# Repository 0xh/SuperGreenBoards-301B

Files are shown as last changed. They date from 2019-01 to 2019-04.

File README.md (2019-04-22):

SuperGreenLab

SuperGreenLab (https://www.reddit.com/r/SuperGreenLab)

# Table of Contents

   * [SuperGreenBoards-301B](#supergreenboards-301b)
   * [SGB.301B Overview](#sgb301b-overview)
   * [Board specifications](#board-specifications)
      * [SGB 36.301B](#sgb-36301b)
      * [SGB 72.301B](#sgb-72301b)
      * [SGB 144.301B](#sgb-144301b)
      * [SB 192.301B](#sb-192301b)
      * [SGB 288.301B](#sgb-288301b)
   * [License](#license)
   * [Creative Commons Warranties Disclaimer](#creative-commons-warranties-disclaimer)

# SuperGreenBoards-301B

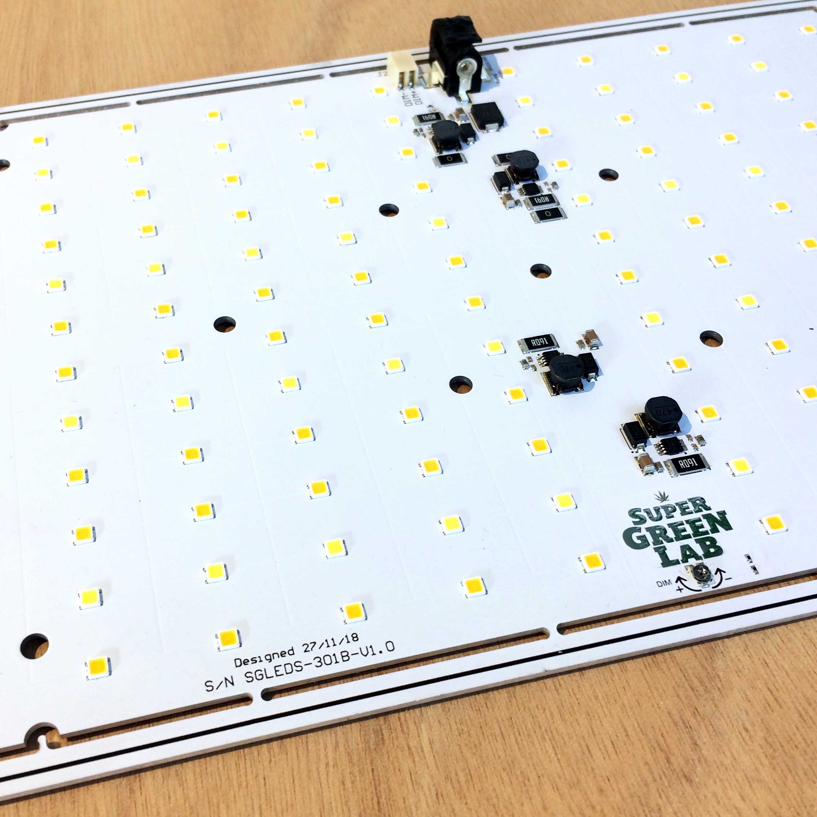
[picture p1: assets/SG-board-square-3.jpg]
SuperGreenLab SuperGreenLeds-301B

First prototype of the SGB.301B family

SGB.301B are aluminium substrate led boards containing up to 288 Samsung's LM301B leds supergreenlab (https://supergreenlab.com/). This open hardware design is licensed under the Creative Commons Attribution-ShareAlike 3.0 Unported License.

Pull requests of relevant issues are warmly welcomed.

# SGB.301B Overview

* **LEDS** : up to 288 Samsung's [LM301B](https://www.samsung.com/led/lighting/mid-power-leds/3030-leds/lm301b/) 220 lm/W, CRI80 leds. Boards are setup with 2/3 2700K leds and 1/3 5000K leds for best grow and flowering performances. (spectum below)
* **ONBOARD LED drivers** (if applicable) : [AL8806MP8-13](https://www.diodes.com/assets/Datasheets/AL8806.pdf) buck step-down, up to 1.5A and 98% efficiency led driver.
* **POWER IN** : Standard 5*2.5mm Barrel/Jack or 3 pins JST-XH [S3B-XH-SM4-TB](http://www.jst-mfg.com/product/detail_e.php?series=277) or [screwless terminal block](https://www.metz-connect.com/us/system/files/productfiles/Data_sheet_SM99S01VBNN04G7_SM99S01VBNN04G7_OFF-031067R.pdf) (see each board specification)
* **DIMMER** : All Boards can be dimmed (see each board specification)
* **ADDITIONAL** : All boards have mouting holes compatible with VESA : 75x75mm, 100x100mm and additional M4 mounting holes on the sides.
* **THERMAL** : Boards are made from Aluminium Substrate panel for best thermal performances. Each boards is designed to be used without heatsink in standard ambient temperature.

**TODO** Add board spectrum

# Board specifications
 
## SGB 36.301B

* **LEDS** : 36 [LM301B](https://www.samsung.com/led/lighting/mid-power-leds/3030-leds/lm301b/) for 4K lumens total
* **ONBOARD LED drivers** : 1 
* **SIZE** : 130mmx110mm (5.1"x4.3")
* **CONNECTOR** : 3 pins JST-XH [S3B-XH-SM4-TB](http://www.jst-mfg.com/product/detail_e.php?series=277) for power and dimmer
* **POWER INPUT** : 24VDC/1A (Constant Voltage), Max Power : 20W. Designed to be powered by supergreenlab's [SGController](https://github.com/supergreenlab/SuperGreenController)
* **DIMMER** : 10V analog or PWM. Designed to be controlled by supergreenlab's [SGController]
* **MOUNTING HOLES** : VESA 75x75mm and 100x100m M4

## SGB 72.301B

* **LEDS** : 72 [LM301B](https://www.samsung.com/led/lighting/mid-power-leds/3030-leds/lm301b/) for 8K lumens total
* **ONBOARD LED drivers** : 2 (36 leds/driver) 
* **SIZE** : 250mmx110mm (9.8"x5.1")
* **CONNECTOR** : 3 pins JST-XH [S3B-XH-SM4-TB](http://www.jst-mfg.com/product/detail_e.php?series=277) for power and dimmer
* **POWER INPUT** : 24VDC/2A (Constant Voltage), Max Power : 40W. Designed to be powered by supergreenlab's [SGController](https://github.com/supergreenlab/SuperGreenController)
* **DIMMER** : 10V analog or PWM. Designed to be controlled by supergreenlab's [SGController](https://github.com/supergreenlab/SuperGreenController)
* **MOUNTING HOLES** : VESA 75x75mm and 100x100m M4, additionnal mounting holes on the side

## SGB 144.301B

* **LEDS** : 144 [LM301B](https://www.samsung.com/led/lighting/mid-power-leds/3030-leds/lm301b/) for 16K lumens total
* **ONBOARD LED drivers** : 4 (36 leds/driver) 
* **SIZE** : 250mmx230mm (9.8"x9")
* **CONNECTOR** : Standard 5*2.5mm Barrel/Jack for power and 3 pins JST-XH [S3B-XH-SM4-TB](http://www.jst-mfg.com/product/detail_e.php?series=277) for power and dimmer
* **POWER** : Input : 24VDC/5A (Constant Voltage Power supply : https://amzn.to/2DNSty4), Max Power : 80W.
* **DIMMER** : 10V analog or PWM. Designed to be controlled by supergreenlab's [SGController](https://github.com/supergreenlab/SuperGreenController)
* **MOUNTING HOLES** : VESA 75x75mm and 100x100m M4, VESA 200x200mm M6, additionnal mounting holes on the side

## SB 192.301B

* **LEDS** : 192 [LM301B](https://www.samsung.com/led/lighting/mid-power-leds/3030-leds/lm301b/) for 20K lumens total
* **ONBOARD LED drivers** : 4 (48 leds/driver) 
* **MCU** : [ESP32-WROOM-32](https://www.espressif.com/en/products/hardware/esp-wroom-32/overview), wifi , bluetooth and BLE microcontroller. Fimrware : [SuperGreenOS](https://github.com/supergreenlab/SuperGreenOS) app : [SuperGreenApp](https://github.com/supergreenlab/SuperGreenApp)
* **SIZE** : 350mmx230mm (13.8"x9")
* **CONNECTOR** : Standard 5*2.5mm Barrel/Jack for power , 2 pins JST-XH [S2B-XH-SM4-TB](http://www.jst-mfg.com/product/detail_e.php?series=277) for Fan/Blower and 4 pins JST-XH [S4B-XH-SM4-TB](http://www.jst-mfg.com/product/detail_e.php?series=277) for sensor
* **POWER** : Input : 24VDC/5A (Constant Voltage Power supply : https://amzn.to/2DNSty4), Max Power : 120W.
* **MOUNTING HOLES** : VESA 75x75mm and 100x100m M4, VESA 200x200mm M6, additionnal mounting holes on the side

## SGB 288.301B

* **LEDS** : 288 [LM301B](https://www.samsung.com/led/lighting/mid-power-leds/3030-leds/lm301b/) for up to 32K total
* **SIZE** : 350mmx250mm (13.8"x9.8")
* **CONNECTORS** : [Screwless terminal block](https://www.metz-connect.com/us/system/files/productfiles/Data_sheet_SM99S01VBNN04G7_SM99S01VBNN04G7_OFF-031067R.pdf) 16-22AWG
* **POWER** : [Power supply guide](https://supergreenlab.com/sg-288301b-driver-guide)
* **MOUNTING HOLES** : VESA 75x75mm and 100x100m M4, VESA 200x200mm M6, additionnal mounting holes on the side

# License

This work is licensed under the Creative Commons Attribution-ShareAlike 3.0 Unported License. To view a copy of this license, visit http://creativecommons.org/licenses/by-sa/3.0/ or send a letter to Creative Commons, PO Box 1866, Mountain View, CA 94042, USA.

# Creative Commons Warranties Disclaimer

UNLESS OTHERWISE MUTUALLY AGREED TO BY THE PARTIES IN WRITING, LICENSOR OFFERS THE WORK AS-IS AND MAKES NO REPRESENTATIONS OR WARRANTIES OF ANY KIND CONCERNING THE WORK, EXPRESS, IMPLIED, STATUTORY OR OTHERWISE, INCLUDING, WITHOUT LIMITATION, WARRANTIES OF TITLE, MERCHANTIBILITY, FITNESS FOR A PARTICULAR PURPOSE, NONINFRINGEMENT, OR THE ABSENCE OF LATENT OR OTHER DEFECTS, ACCURACY, OR THE PRESENCE OF ABSENCE OF ERRORS, WHETHER OR NOT DISCOVERABLE. SOME JURISDICTIONS DO NOT ALLOW THE EXCLUSION OF IMPLIED WARRANTIES, SO SUCH EXCLUSION MAY NOT APPLY TO YOU.

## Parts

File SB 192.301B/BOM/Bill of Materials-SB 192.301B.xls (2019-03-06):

Comment | Description | Designator | Footprint | LibRef | Manufacturer | Manufacturer Part Number | Quantity
10uF | Multilayer Ceramic Capacitors MLCC - SMD/SMT 10uF 50V X5R +/-20% 1206 Gen Purp | C1, C9, C14 | 1206 | C 10uF 50V X5R +/-20% 1206 Gen Purp | Taiyo Yuden | UMK316BBJ106ML-T | 3.0
0.1uF | Multilayer Ceramic Capacitors MLCC - SMD/SMT 100nF 50V X7R 10% | C2, C3, C10 | 0603 | C 0.1uF 50V X7R 10% | Yageo | CC0603KRX7R9BB104 | 3.0
0.1uF | MLCC - SMD/SMT 50V 0.1uF X7R 1206 20% | C4_D_0, C4_D_1, C4_D_2, C4_D_3 | 1206 | C 0.1uF 50V X7R 1206 20% | KEMET | C1206C104M5RACTU | 4.0
4.7uF | MLCC - SMD/SMT 1206 4.7uF 50volts X7R +/-10% Soft Term | C5_D_0, C5_D_1, C5_D_2, C5_D_3 | 1206 | C 1206 4.7uF 50volts X7R +/-10% | Murata Electronics | GRJ31CR71H475KE11L | 4.0
1.5nF | MLCC - SMD/SMT 50V 1500pF 0603 X7R 10% | C6_D_0, C6_D_1, C6_D_2, C6_D_3, C7_D_0, C7_D_1, C7_D_2, C7_D_3 | 0603 | C 1500pF 50V 0603 X7R 10% | KEMET | C0603C152K5RAC | 8.0
1uF | MLCC - SMD/SMT 1uF 50V X7R +/-10% 0603 Gen Purp | C8_D_0, C8_D_1, C8_D_2, C8_D_3 | 0603 | C 1uF 50V X7R +/-10% 0603 | Taiyo Yuden | UMK107AB7105KA-T | 4.0
22uF | Multilayer Ceramic Capacitors MLCC - SMD/SMT 0805 25Vdc 22uF X5R 20% | C11, C12 | 0805 | C 22uF 25V X5R 20% | Murata Electronics | GRT21BR61E226ME13L | 2.0
22nF | Multilayer Ceramic Capacitors MLCC - SMD/SMT 22nF 50V X7R 10% | C13 | 0603 | C 22nF 50V X7R 10% | Yageo | CC0603KRX7R9BB223 | 1.0
B240A | Schottky Diodes & Rectifiers 40V 2A | D1_D_0, D1_D_1, D1_D_2, D1_D_3 | SMA | B240A-13-F | Diodes Incorporated | B240A-13-F | 4.0
MBR230LSFT1G | Schottky Diodes & Rectifiers 2A 30V SCHOTTKY | D2 | SOD-123LF | MBR230LSFT1G | ON Semiconductor | MBR230LSFT1G | 1.0
TAG connect |  | J1 | TC2050-IDC | TC2050 |  |  | 1.0
BARREL | CONN PWR JACK 2.5X5.5MM SOLDER | J2 | PJ-036BH-SMT-TR | PJ-036BH-SMT-TR | CUI Inc. | PJ-036BH-SMT-TR | 1.0
JST XH4 |  | J3 | JST XH-4 Right angle -SMD | S4B-XH-SM4-TB |  |  | 1.0
JST XH 2 |  | J4 | JST XH-2 Right angle -SMD | S2B-XH-SM4-TB |  |  | 1.0
ASMB-KTF0-0A306 | Standard LEDs - SMD 2220 PLCC4 Tricolor | L1 | ASMB-KTF0-0A306 | ASMB-KTF0-0A306 | Broadcom / Avago | ASMB-KTF0-0A306 | 1.0
47uH | Fixed Inductors 47uH 20% 1.6A shd SMD AEC-Q200 | L2_D_0, L2_D_1, L2_D_2, L2_D_3 | SRN6045TA | SRN6045TA-470M | Bourns | SRN6045TA-470M | 4.0
4.7uH | Fixed Inductors 8030 4.7uH 28.6mOhms +/-20%Tol 3600mA | L3 | 8030 | NRS8030T4R7MJGJ | Taiyo Yuden | NRS8030T4R7MJGJ | 1.0
2700K | LED MID PWR LM301B 3MMX3MM | LED1_L_0, LED1_L_1, LED1_L_2, LED1_L_3, LED3_L_0, LED3_L_1, LED3_L_2, LED3_L_3, LED4_L_0, LED4_L_1, LED4_L_2, LED4_L_3, LED6_L_0, LED6_L_1, LED6_L_2, LED6_L_3, LED7_L_0, LED7_L_1, LED7_L_2, LED7_L_3, LED9_L_0, LED9_L_1, LED9_L_2, LED9_L_3, LED10_L_0, LED10_L_1, LED10_L_2, LED10_L_3, LED12_L_0, LED12_L_1, LED12_L_2, LED12_L_3, LED13_L_0, LED13_L_1, LED13_L_2, LED13_L_3, LED15_L_0, LED15_L_1, LED15_L_2, LED15_L_3, LED16_L_0, LED16_L_1, LED16_L_2, LED16_L_3, LED18_L_0, LED18_L_1, LED18_L_2, LED18_L_3, LED19_L_0, LED19_L_1, LED19_L_2, LED19_L_3, LED21_L_0, LED21_L_1, LED21_L_2, LED21_L_3, LED22_L_0, LED22_L_1, LED22_L_2, LED22_L_3, LED24_L_0, LED24_L_1, LED24_L_2, LED24_L_3, LED25_L_0, LED25_L_1, LED25_L_2, LED25_L_3, LED27_L_0, LED27_L_1, LED27_L_2, LED27_L_3, LED28_L_0, LED28_L_1, LED28_L_2, LED28_L_3, LED30_L_0, LED30_L_1, LED30_L_2, LED30_L_3, LED31_L_0, LED31_L_1, LED31_L_2, LED31_L_3, LED33_L_0, LED33_L_1, LED33_L_2, LED33_L_3, LED34_L_0, LED34_L_1, LED34_L_2, LED34_L_3, LED36_L_0, LED36_L_1, LED36_L_2, LED36_L_3, LED37_L_0, LED37_L_1, LED37_L_2, LED37_L_3, LED39_L_0, LED39_L_1, LED39_L_2, LED39_L_3, LED40_L_0, LED40_L_1, LED40_L_2, LED40_L_3, LED42_L_0, LED42_L_1, LED42_L_2, LED42_L_3, LED43_L_0, LED43_L_1, LED43_L_2, LED43_L_3, LED45_L_0, LED45_L_1, LED45_L_2, LED45_L_3, LED46_L_0, LED46_L_1, LED46_L_2, LED46_L_3, LED48_L_0, LED48_L_1, LED48_L_2, LED48_L_3 | LM301B | SPMWHD32AMD5XAW0S0 | Samsung Semiconductor, Inc. | SPMWHD32AMD5XAW0S0 | 128.0
5000K | LED MID PWR LM301B 3MMX3MM | LED2_L_0, LED2_L_1, LED2_L_2, LED2_L_3, LED5_L_0, LED5_L_1, LED5_L_2, LED5_L_3, LED8_L_0, LED8_L_1, LED8_L_2, LED8_L_3, LED11_L_0, LED11_L_1, LED11_L_2, LED11_L_3, LED14_L_0, LED14_L_1, LED14_L_2, LED14_L_3, LED17_L_0, LED17_L_1, LED17_L_2, LED17_L_3, LED20_L_0, LED20_L_1, LED20_L_2, LED20_L_3, LED23_L_0, LED23_L_1, LED23_L_2, LED23_L_3, LED26_L_0, LED26_L_1, LED26_L_2, LED26_L_3, LED29_L_0, LED29_L_1, LED29_L_2, LED29_L_3, LED32_L_0, LED32_L_1, LED32_L_2, LED32_L_3, LED35_L_0, LED35_L_1, LED35_L_2, LED35_L_3, LED38_L_0, LED38_L_1, LED38_L_2, LED38_L_3, LED41_L_0, LED41_L_1, LED41_L_2, LED41_L_3, LED44_L_0, LED44_L_1, LED44_L_2, LED44_L_3, LED47_L_0, LED47_L_1, LED47_L_2, LED47_L_3 | LM301B | SPMWHD32AMD5XAR0S0 | Samsung Semiconductor, Inc. | SPMWHD32AMD5XAR0S0 | 64.0
DMN3404L-7 | MOSFET N-CHANNEL ENHANCEMENT MODE | Q1 | SOT23 | DMN3404L-7 | Diodes Incorporated | DMN3404L-7 | 1.0
10K | Thick Film Resistors - SMD 10K OHM 1% | R1, R2, R11, R12, R13 | 0603 | R SMD 10K 1% 0603 | Yageo | RC0603FR-0710KL | 5.0
24R | Thin Film Resistors - SMD 1/10W 24 ohm 1% 50ppm | R3 | 0603 | R SMD 1/10W 24 ohm 1% 50ppm | Yageo | RT0603FRE0724RL | 1.0
91R | Thin Film Resistors - SMD 1/10W 91 ohm 1% 50ppm | R4 | 0603 | R SMD 1/10W 91 ohm 1% 50ppm | Yageo | RT0603FRE0791RL | 1.0
0.07R | Current Sense Resistors - SMD 0.07 Ohm 1% 1W | R6_D_0, R6_D_1, R6_D_2, R6_D_3 | 2512 | R SMD 0.07 Ohm 1% 1W | Yageo | RL2512FK-070R075L | 4.0
0R | Thick Film Resistors - SMD 0 ohm 1% 200V General Purpose | R7, R8, R9, R10, R14, R15 | 2512 | R SMD 0 ohm 1% 200V | Yageo | RC2512FK-070RL | 6.0
AL8806MP8-13 | LED Display Drivers HIGH EFF 30V 1.5A 6V TO 30V 8 LED | U1_D_0, U1_D_1, U1_D_2, U1_D_3 | MSOP-8EP | AL8806MP8-13 | Diodes Incorporated | AL8806MP8-13 | 4.0
ESP-WROOM-32 |  | U2 | ESP-WROOM-32 | ESP-WROOM-32 |  |  | 1.0
TS30041-M033 | Switching Voltage Regulators 1A 3.3V Current-Mode Sync. Buck Converter | U3 | QFN 3x3 16 | TS30041-M033QFNR | Semtech | TS30041-M033QFNR | 1.0
MCP9701AT-E/TT | Board Mount Temperature Sensors Linear Active Thermister IC | U4 | SOT23 | MCP9701AT-E/TT | Microchip Technology | MCP9701AT-E/TT | 1.0

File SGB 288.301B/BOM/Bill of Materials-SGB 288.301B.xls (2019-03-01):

Comment | Description | Designator | Footprint | LibRef | Manufacturer | Manufacturer Part Number | Quantity
Red | TERM BLOCK 1POS SIDE ENTRY SMD | J1, J2 | SM99S01VBNN00G7 | SM99S01VBNN04G7 | METZ CONNECT USA Inc. | SM99S01VBNN04G7 | 2.0
Black | TERM BLOCK 1POS SIDE ENTRY SMD | J3, J4 | SM99S01VBNN00G7 | SM99S01VBNN00G7 | METZ CONNECT USA Inc. | SM99S01VBNN00G7 | 2.0
2700K | LED MID PWR LM301B 3MMX3MM | LED1_L_0, LED1_L_1, LED1_L_2, LED1_L_3, LED1_L_4, LED1_L_5, LED1_L_6, LED1_L_7, LED1_L_8, LED1_L_9, LED1_L_10, LED1_L_11, LED1_L_12, LED1_L_13, LED1_L_14, LED1_L_15, LED2_L_0, LED2_L_1, LED2_L_2, LED2_L_3, LED2_L_4, LED2_L_5, LED2_L_6, LED2_L_7, LED2_L_8, LED2_L_9, LED2_L_10, LED2_L_11, LED2_L_12, LED2_L_13, LED2_L_14, LED2_L_15, LED3_L_0, LED3_L_1, LED3_L_2, LED3_L_3, LED3_L_4, LED3_L_5, LED3_L_6, LED3_L_7, LED3_L_8, LED3_L_9, LED3_L_10, LED3_L_11, LED3_L_12, LED3_L_13, LED3_L_14, LED3_L_15, LED6_L_0, LED6_L_1, LED6_L_2, LED6_L_3, LED6_L_4, LED6_L_5, LED6_L_6, LED6_L_7, LED6_L_8, LED6_L_9, LED6_L_10, LED6_L_11, LED6_L_12, LED6_L_13, LED6_L_14, LED6_L_15, LED7_L_0, LED7_L_1, LED7_L_2, LED7_L_3, LED7_L_4, LED7_L_5, LED7_L_6, LED7_L_7, LED7_L_8, LED7_L_9, LED7_L_10, LED7_L_11, LED7_L_12, LED7_L_13, LED7_L_14, LED7_L_15, LED8_L_0, LED8_L_1, LED8_L_2, LED8_L_3, LED8_L_4, LED8_L_5, LED8_L_6, LED8_L_7, LED8_L_8, LED8_L_9, LED8_L_10, LED8_L_11, LED8_L_12, LED8_L_13, LED8_L_14, LED8_L_15, LED11_L_0, LED11_L_1, LED11_L_2, LED11_L_3, LED11_L_4, LED11_L_5, LED11_L_6, LED11_L_7, LED11_L_8, LED11_L_9, LED11_L_10, LED11_L_11, LED11_L_12, LED11_L_13, LED11_L_14, LED11_L_15, LED12_L_0, LED12_L_1, LED12_L_2, LED12_L_3, LED12_L_4, LED12_L_5, LED12_L_6, LED12_L_7, LED12_L_8, LED12_L_9, LED12_L_10, LED12_L_11, LED12_L_12, LED12_L_13, LED12_L_14, LED12_L_15, LED13_L_0, LED13_L_1, LED13_L_2, LED13_L_3, LED13_L_4, LED13_L_5, LED13_L_6, LED13_L_7, LED13_L_8, LED13_L_9, LED13_L_10, LED13_L_11, LED1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 | LM301B | SPMWHD32AMD5XAW0S0 | Samsung Semiconductor, Inc. | SPMWHD32AMD5XAW0S0 | 192.0
5000K | LED MID PWR LM301B 3MMX3MM | LED4_L_0, LED4_L_1, LED4_L_2, LED4_L_3, LED4_L_4, LED4_L_5, LED4_L_6, LED4_L_7, LED4_L_8, LED4_L_9, LED4_L_10, LED4_L_11, LED4_L_12, LED4_L_13, LED4_L_14, LED4_L_15, LED5_L_0, LED5_L_1, LED5_L_2, LED5_L_3, LED5_L_4, LED5_L_5, LED5_L_6, LED5_L_7, LED5_L_8, LED5_L_9, LED5_L_10, LED5_L_11, LED5_L_12, LED5_L_13, LED5_L_14, LED5_L_15, LED9_L_0, LED9_L_1, LED9_L_2, LED9_L_3, LED9_L_4, LED9_L_5, LED9_L_6, LED9_L_7, LED9_L_8, LED9_L_9, LED9_L_10, LED9_L_11, LED9_L_12, LED9_L_13, LED9_L_14, LED9_L_15, LED10_L_0, LED10_L_1, LED10_L_2, LED10_L_3, LED10_L_4, LED10_L_5, LED10_L_6, LED10_L_7, LED10_L_8, LED10_L_9, LED10_L_10, LED10_L_11, LED10_L_12, LED10_L_13, LED10_L_14, LED10_L_15, LED14_L_0, LED14_L_1, LED14_L_2, LED14_L_3, LED14_L_4, LED14_L_5, LED14_L_6, LED14_L_7, LED14_L_8, LED14_L_9, LED14_L_10, LED14_L_11, LED14_L_12, LED14_L_13, LED14_L_14, LED14_L_15, LED15_L_0, LED15_L_1, LED15_L_2, LED15_L_3, LED15_L_4, LED15_L_5, LED15_L_6, LED15_L_7, LED15_L_8, LED15_L_9, LED15_L_10, LED15_L_11, LED15_L_12, LED15_L_13, LED15_L_14, LED15_L_15 | LM301B | SPMWHD32AMD5XAR0S0 | Samsung Semiconductor, Inc. | SPMWHD32AMD5XAR0S0 | 96.0
pad |  | P1, P2, P3, P4 | Pads | pad |  |  | 4.0

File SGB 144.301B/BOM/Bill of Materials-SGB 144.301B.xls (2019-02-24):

Comment | Description | Designator | Footprint | LibRef | Manufacturer | Manufacturer Part Number | Quantity
0.1uF | MLCC - SMD/SMT 50V 0.1uF X7R 1206 20% | C1_D1, C1_D2, C1_D3, C1_D4 | 1206 | C 0.1uF 50V X7R 1206 20% | KEMET | C1206C104M5RACTU | 4.0
4.7uF | MLCC - SMD/SMT 1206 4.7uF 50volts X7R +/-10% Soft Term | C2_D1, C2_D2, C2_D3, C2_D4 | 1206 | C 1206 4.7uF 50volts X7R +/-10% | Murata Electronics | GRJ31CR71H475KE11L | 4.0
1.5nF | MLCC - SMD/SMT 50V 1500pF 0603 X7R 10% | C3_D1, C3_D2, C3_D3, C3_D4, C4_D1, C4_D2, C4_D3, C4_D4 | 0603 | C 1500pF 50V 0603 X7R 10% | KEMET | C0603C152K5RAC | 8.0
1uF | MLCC - SMD/SMT 1uF 50V X7R +/-10% 0603 Gen Purp | C5_D1, C5_D2, C5_D3, C5_D4 | 0603 | C 1uF 50V X7R +/-10% 0603 | Taiyo Yuden | UMK107AB7105KA-T | 4.0
B240A | Schottky Diodes & Rectifiers 40V 2A | D1_D1, D1_D2, D1_D3, D1_D4 | SMA | B240A-13-F | Diodes Incorporated | B240A-13-F | 4.0
JST 3 | CONN HEADER XH SMD 3POS 2.5MM | J1 | JST XH-3 right angle | S3B-XH-SM4-TB(LF)(SN) | JST Sales America Inc. | S3B-XH-SM4-TB(LF)(SN) | 1.0
BARREL | CONN PWR JACK 2.5X5.5MM SOLDER | J2 | PJ-036BH-SMT-TR | PJ-036BH-SMT-TR | CUI Inc. | PJ-036BH-SMT-TR | 1.0
47uH | Fixed Inductors 47uH 20% 1.6A shd SMD AEC-Q200 | L1_D1, L1_D2, L1_D3, L1_D4 | SRN6045TA | SRN6045TA-470M | Bourns | SRN6045TA-470M | 4.0
2700K | LED MID PWR LM301B 3MMX3MM | LED1_L1, LED1_L2, LED1_L3, LED1_L4, LED3_L1, LED3_L2, LED3_L3, LED3_L4, LED4_L1, LED4_L2, LED4_L3, LED4_L4, LED6_L1, LED6_L2, LED6_L3, LED6_L4, LED7_L1, LED7_L2, LED7_L3, LED7_L4, LED9_L1, LED9_L2, LED9_L3, LED9_L4, LED10_L1, LED10_L2, LED10_L3, LED10_L4, LED12_L1, LED12_L2, LED12_L3, LED12_L4, LED13_L1, LED13_L2, LED13_L3, LED13_L4, LED15_L1, LED15_L2, LED15_L3, LED15_L4, LED16_L1, LED16_L2, LED16_L3, LED16_L4, LED18_L1, LED18_L2, LED18_L3, LED18_L4, LED19_L1, LED19_L2, LED19_L3, LED19_L4, LED21_L1, LED21_L2, LED21_L3, LED21_L4, LED22_L1, LED22_L2, LED22_L3, LED22_L4, LED24_L1, LED24_L2, LED24_L3, LED24_L4, LED25_L1, LED25_L2, LED25_L3, LED25_L4, LED27_L1, LED27_L2, LED27_L3, LED27_L4, LED28_L1, LED28_L2, LED28_L3, LED28_L4, LED30_L1, LED30_L2, LED30_L3, LED30_L4, LED31_L1, LED31_L2, LED31_L3, LED31_L4, LED33_L1, LED33_L2, LED33_L3, LED33_L4, LED34_L1, LED34_L2, LED34_L3, LED34_L4, LED36_L1, LED36_L2, LED36_L3, LED36_L4 | LM301B | SPMWHD32AMD5XAW0S0 | Samsung Semiconductor, Inc. | SPMWHD32AMD5XAW0S0 | 96.0
5000K | LED MID PWR LM301B 3MMX3MM | LED2_L1, LED2_L2, LED2_L3, LED2_L4, LED5_L1, LED5_L2, LED5_L3, LED5_L4, LED8_L1, LED8_L2, LED8_L3, LED8_L4, LED11_L1, LED11_L2, LED11_L3, LED11_L4, LED14_L1, LED14_L2, LED14_L3, LED14_L4, LED17_L1, LED17_L2, LED17_L3, LED17_L4, LED20_L1, LED20_L2, LED20_L3, LED20_L4, LED23_L1, LED23_L2, LED23_L3, LED23_L4, LED26_L1, LED26_L2, LED26_L3, LED26_L4, LED29_L1, LED29_L2, LED29_L3, LED29_L4, LED32_L1, LED32_L2, LED32_L3, LED32_L4, LED35_L1, LED35_L2, LED35_L3, LED35_L4 | LM301B | SPMWHD32AMD5XAR0S0 | Samsung Semiconductor, Inc. | SPMWHD32AMD5XAR0S0 | 48.0
0.1R | Current Sense Resistors - SMD 0.1ohm 1% 1W | R1_D1, R1_D2, R1_D3, R1_D4 | 2512 | RL2512FK-070R1L | Yageo | RL2512FK-070R1L | 4.0
51K | Thin Film Resistors - SMD 1/10W 51K ohm 1% 50ppm | R2 | 0603 | R SMD 51K 1% 50ppm | Yageo | RT0603FRE0751KL | 1.0
10K | Thick Film Resistors - SMD 10K OHM 1% | R3 | 0603 | R SMD 10K 1% 0603 | Yageo | RC0603FR-0710KL | 1.0
0R | Thick Film Resistors - SMD 0 ohm 1% 200V General Purpose | R4, R6, R7, R8 | 2512 | R SMD 0 ohm 1% 200V | Yageo | RC2512FK-070RL | 4.0
30K | Thick Film Resistors - SMD 30K OHM 1% | R5 | 0603 | R SMD 30K 1% 0603 | Yageo | RC0603FR-0730KL | 1.0
AL8806MP8-13 | LED Display Drivers HIGH EFF 30V 1.5A 6V TO 30V 8 LED | U1_D1, U1_D2, U1_D3, U1_D4 | MSOP-8EP | AL8806MP8-13 | Diodes Incorporated | AL8806MP8-13 | 4.0

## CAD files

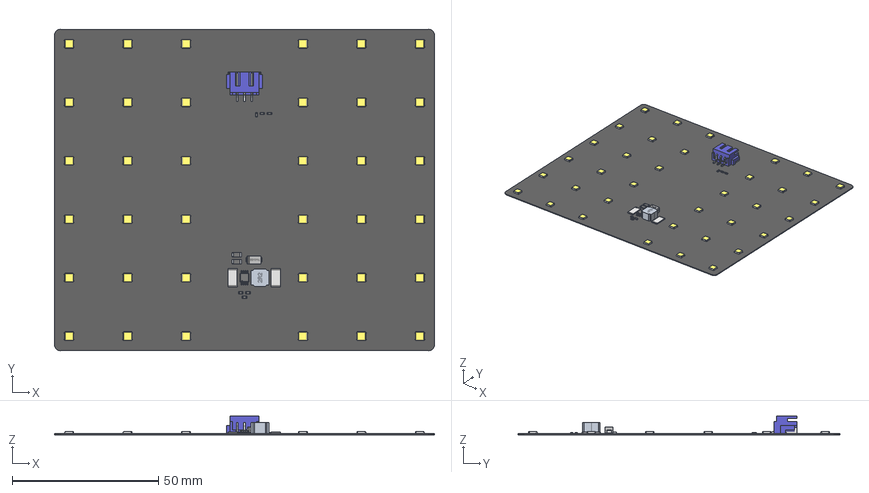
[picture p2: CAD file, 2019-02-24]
SGB 36.301B/ExportSTEP/36.301B.step
130.0 x 110.0 x 6.39 mm
Board
CircuitWorks-RESISTOR_2512 x 2
User_Library-CR1608-0603 x 6
User_Library-CR3216-1206 x 2
User_Library-DO-214AC(SMA)
SRN6045TA
LM301B_170705 x 36
User_Library-msop-8
S3B-XH-SM4-TB

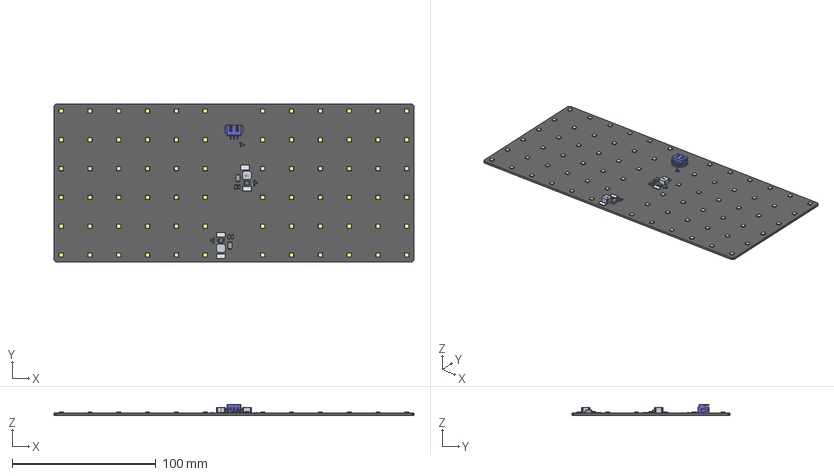
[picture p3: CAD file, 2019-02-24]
SGB 72.301B/ExportSTEP/72.301B.step
250.0 x 110.0 x 7.57 mm
Board
CircuitWorks-RESISTOR_2512 x 4
User_Library-msop-8 x 2
LM301B_170705 x 72
SRN6045TA x 2
User_Library-DO-214AC(SMA) x 2
User_Library-CR1608-0603 x 9
User_Library-CR3216-1206 x 4
S3B-XH-SM4-TB

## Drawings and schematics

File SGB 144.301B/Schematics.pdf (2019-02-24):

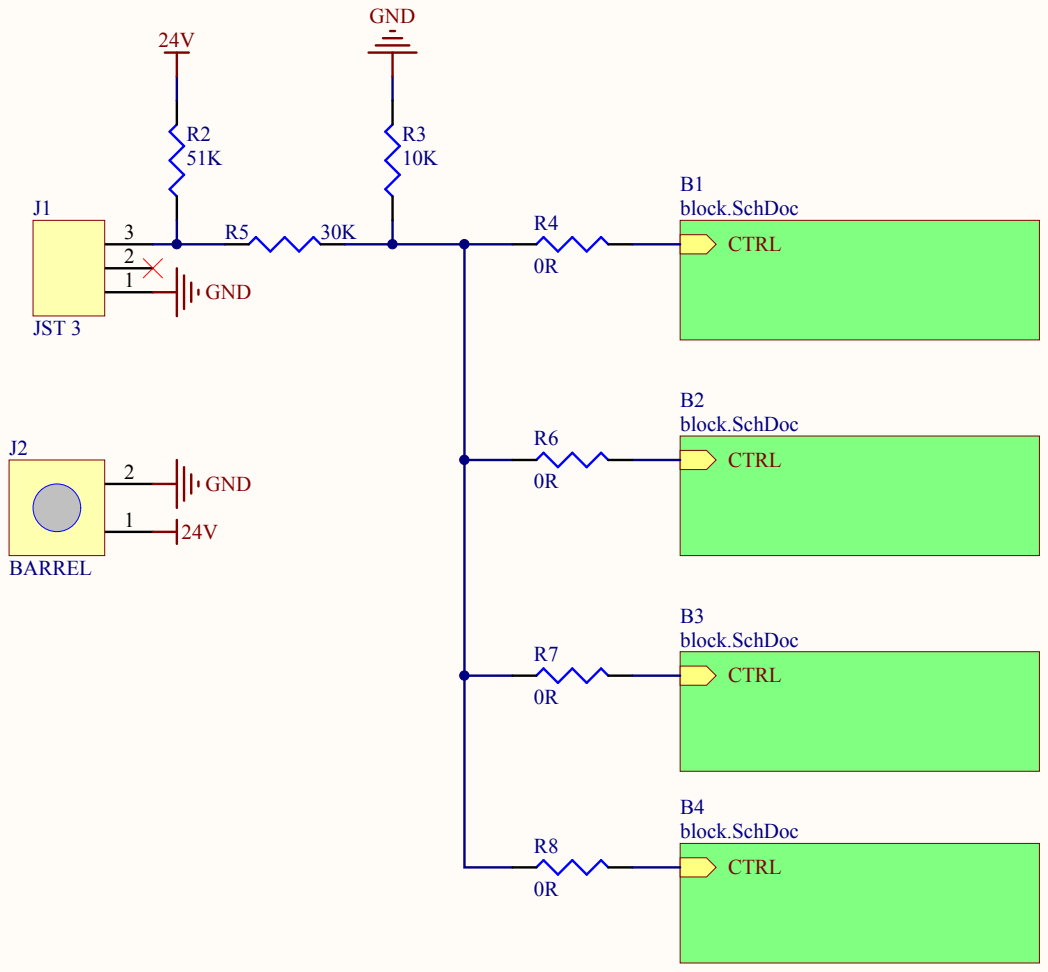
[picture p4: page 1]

Sheet 1 of 4 | Engineer : Charles Passet
Date : 24/02/2019 | Revision :V2.0

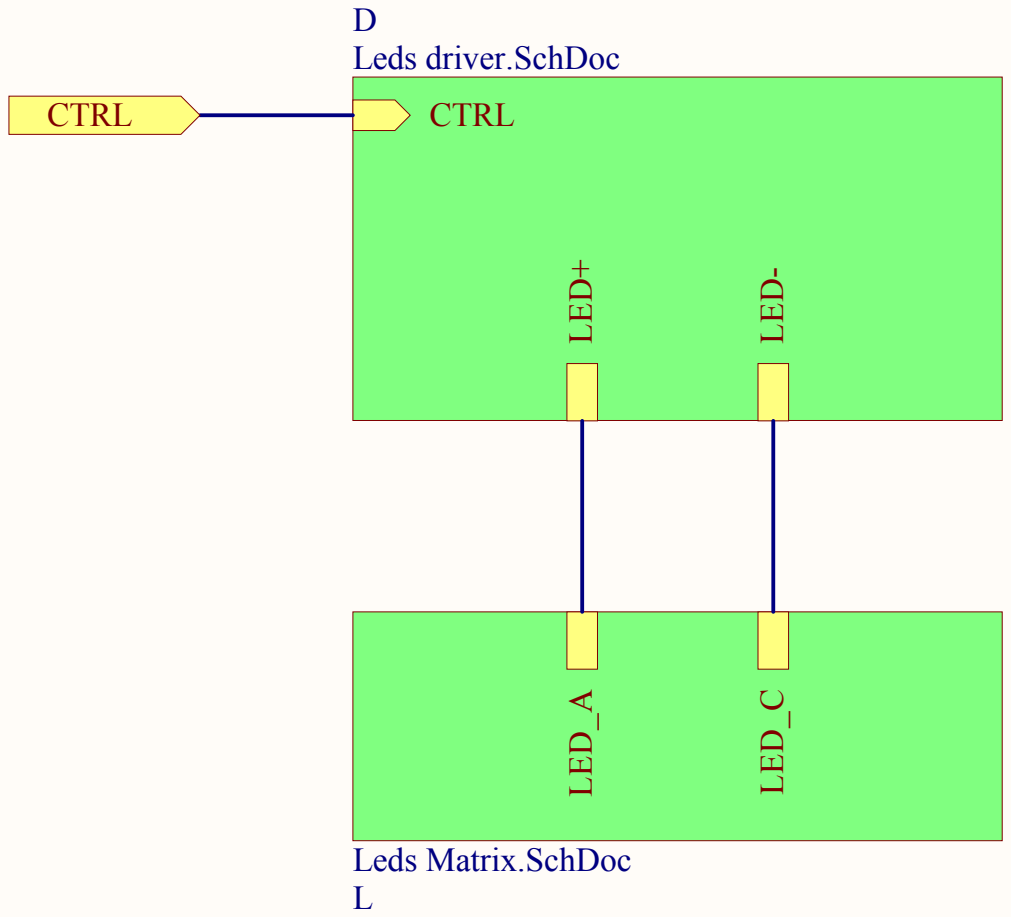
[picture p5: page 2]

Sheet 2 of 4 | Engineer : Charles Passet
Date : 24/02/2019 | Revision :V2.0

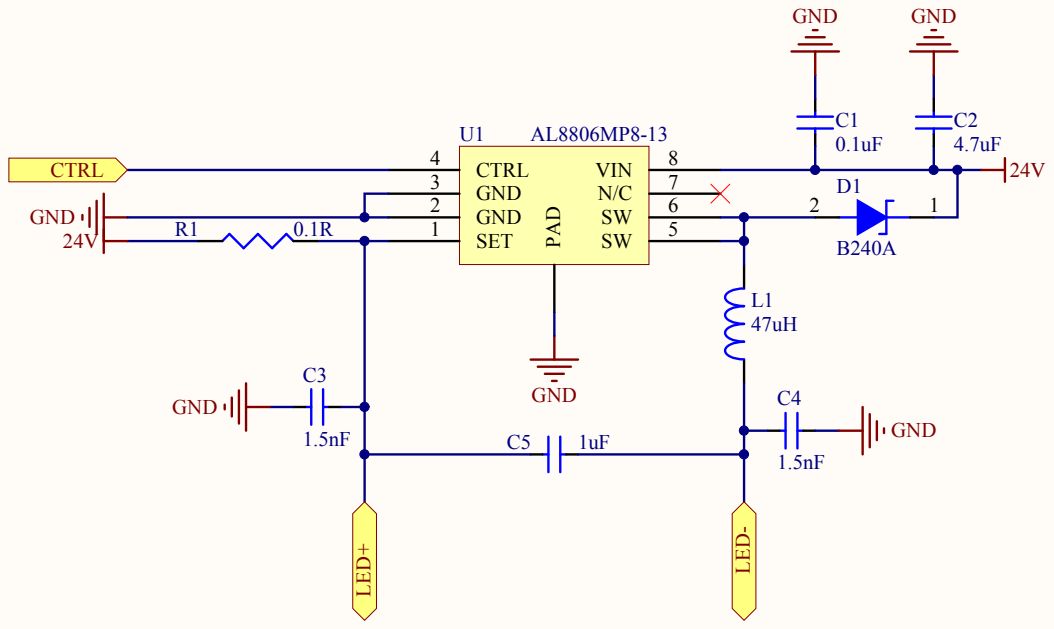
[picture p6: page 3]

Sheet 3 of 4 | Engineer : Charles Passet
Date : 24/02/2019 | Revision :V2.0

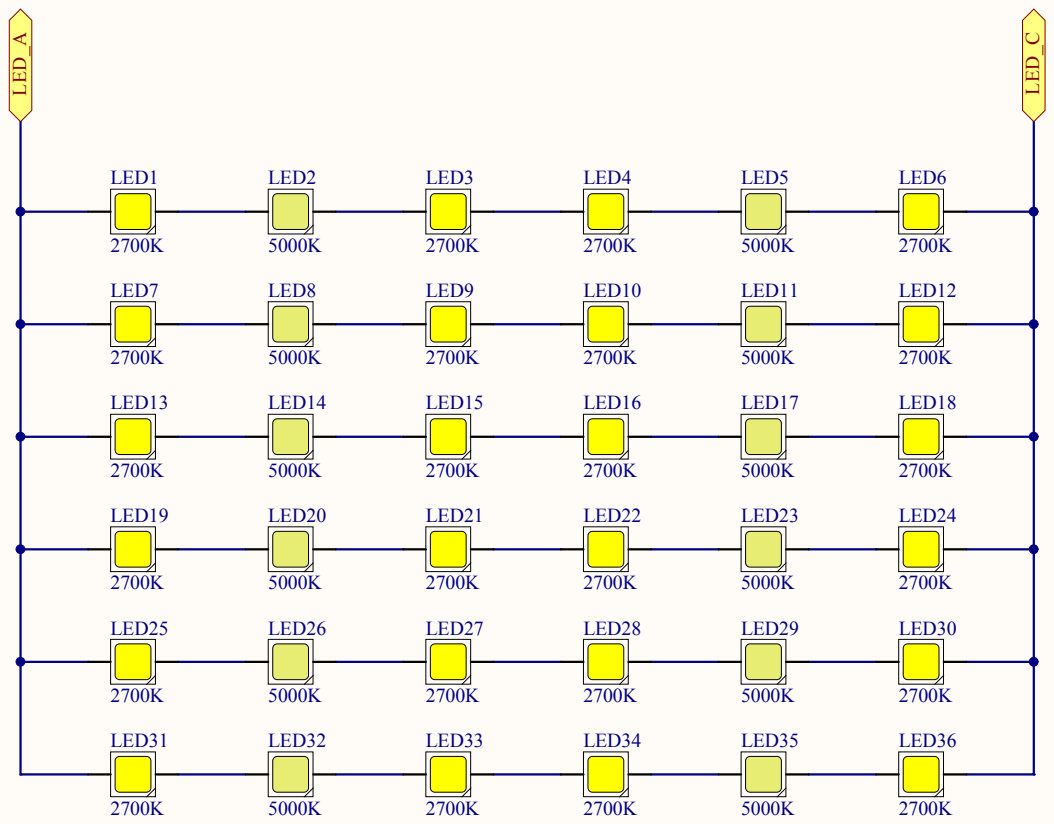
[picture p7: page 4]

Sheet 4 of 4 | Engineer : Charles Passet
Date : 24/02/2019 | Revision :2.0

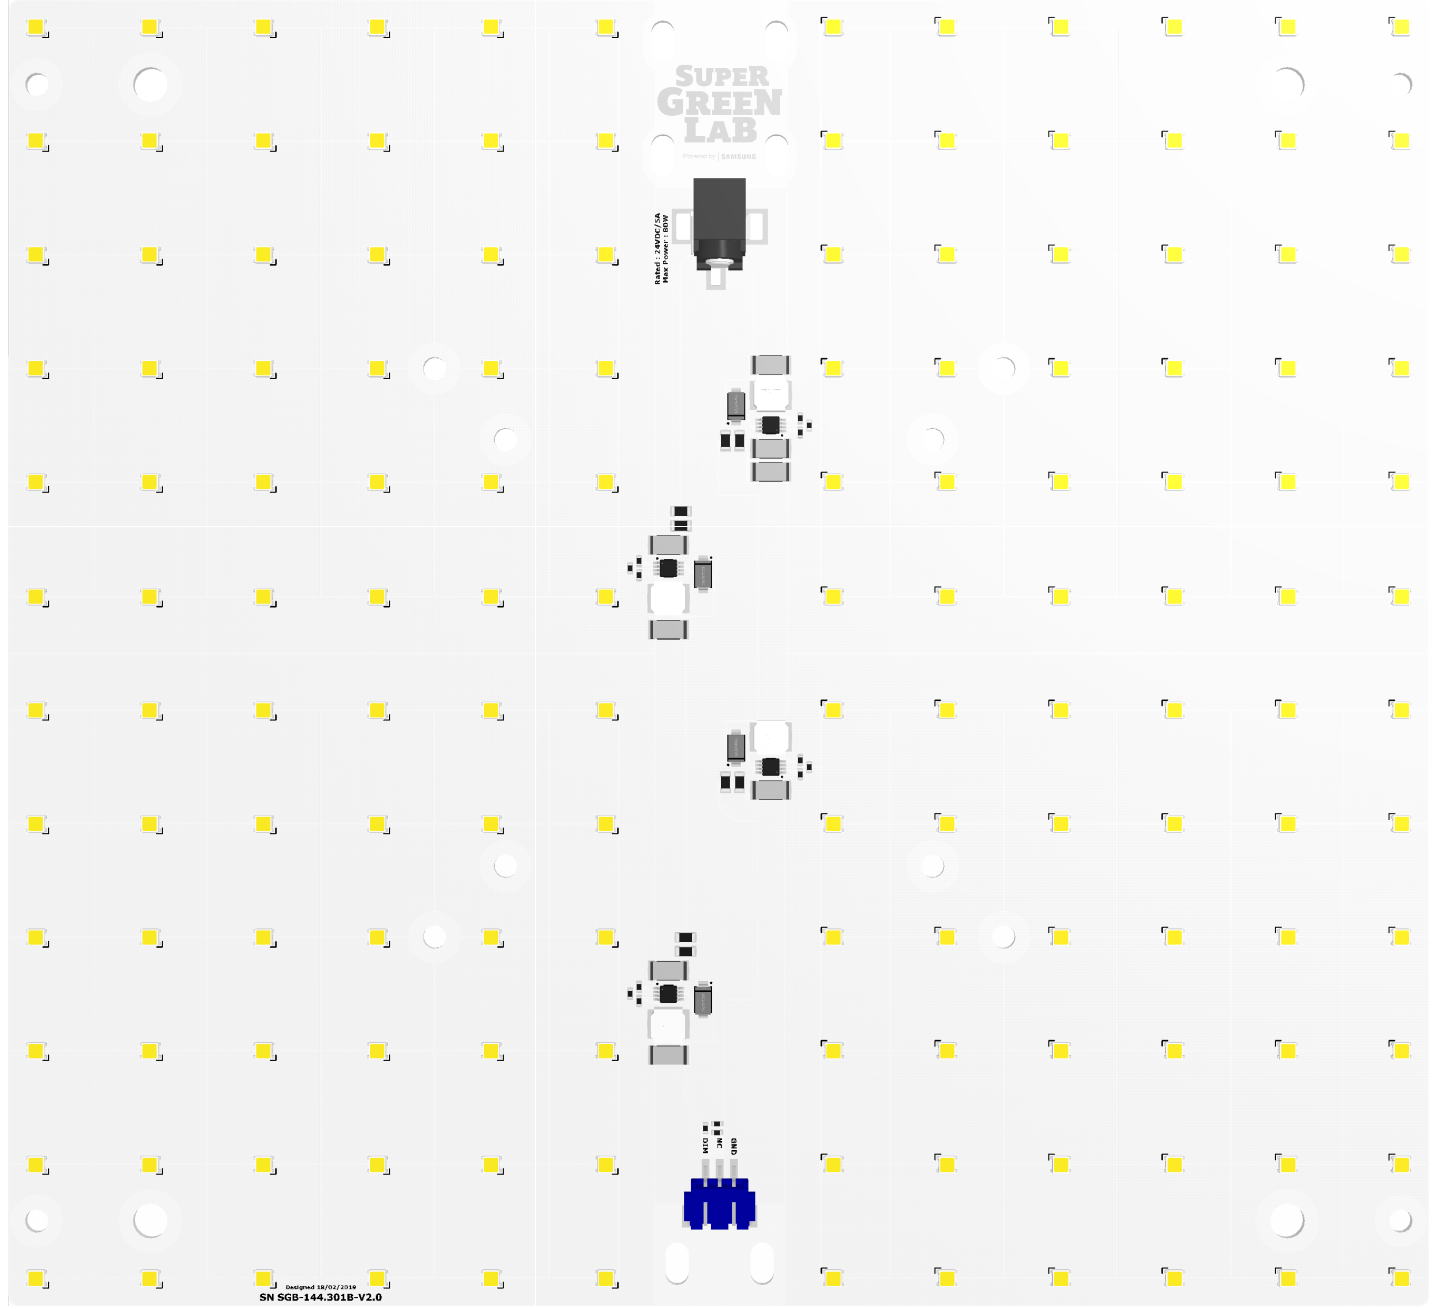
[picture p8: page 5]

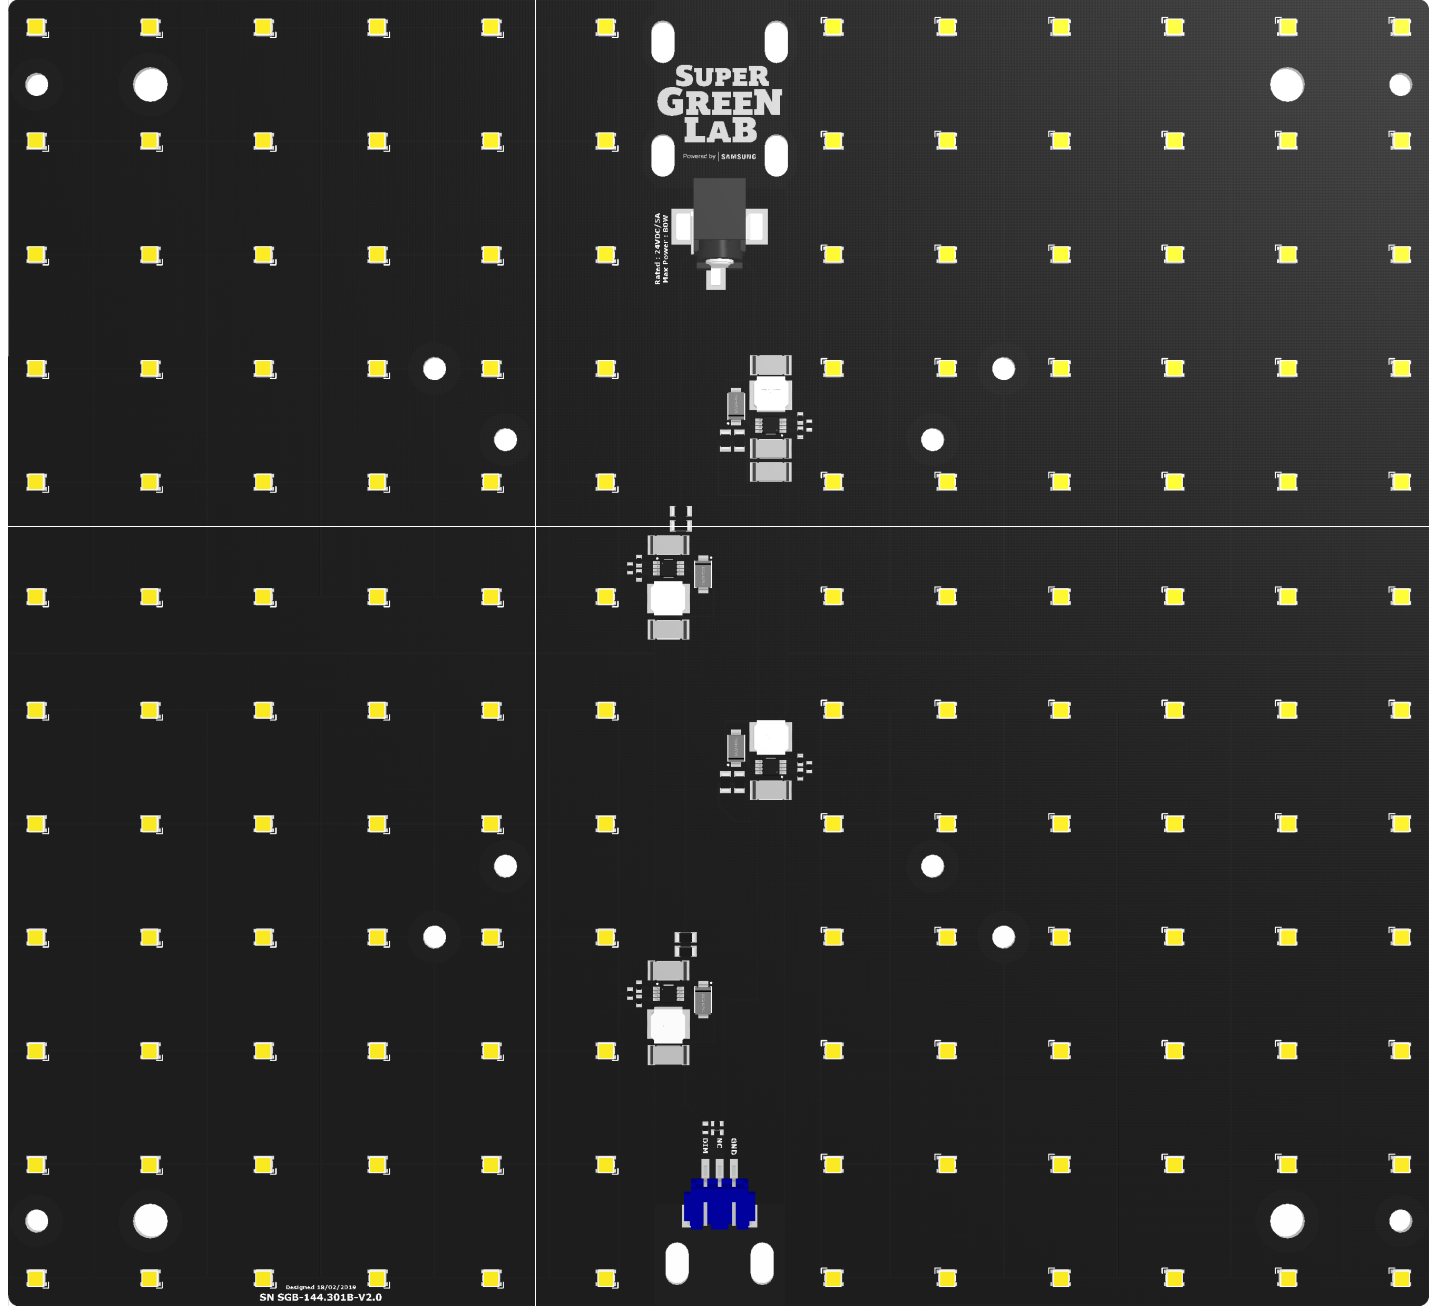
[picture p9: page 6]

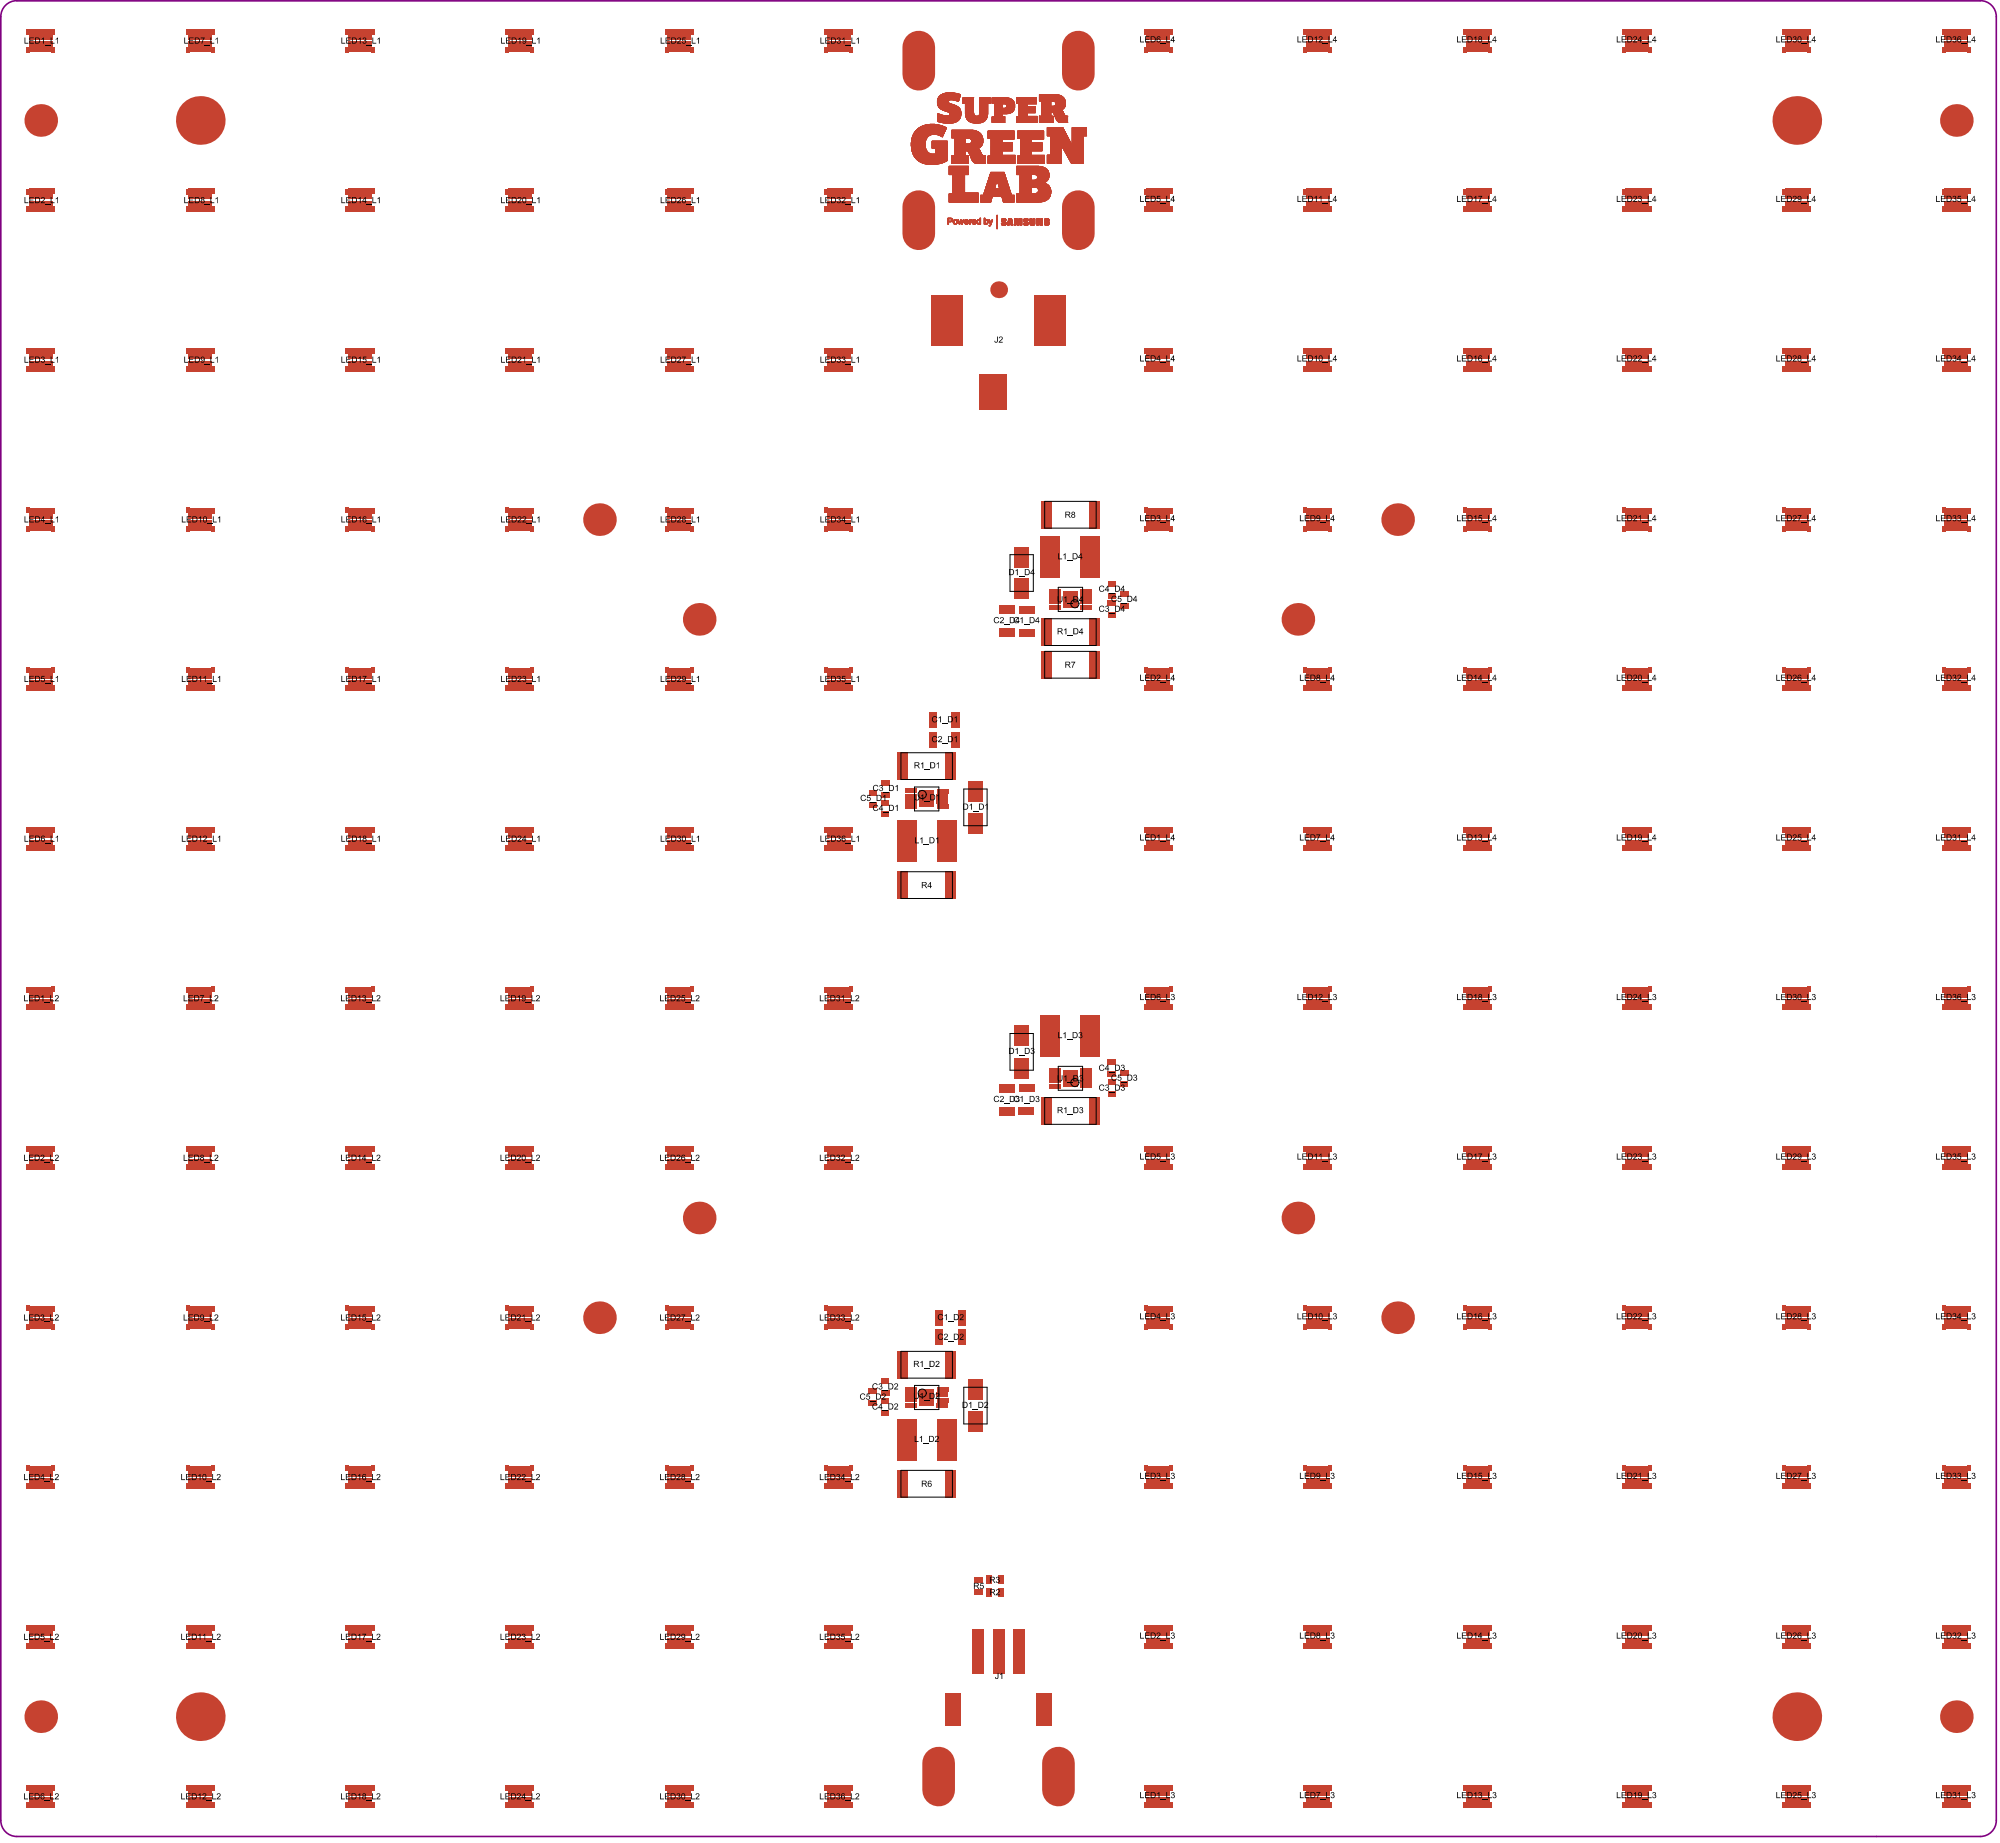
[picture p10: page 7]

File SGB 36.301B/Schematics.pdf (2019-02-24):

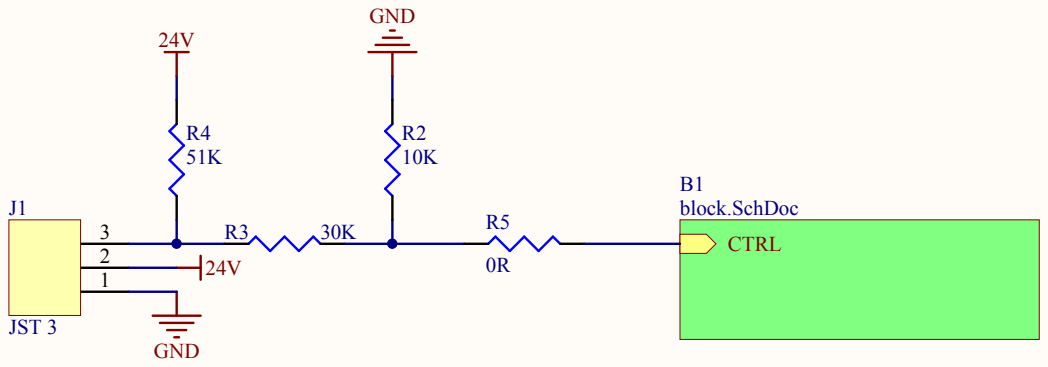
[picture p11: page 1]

Sheet 1 of 4 | Engineer : Charles Passet
Date : 24/02/2019 | Revision :V2.0


Sheet 2 of 4 | Engineer : Charles Passet
Date : 24/02/2019 | Revision :V2.0


Sheet 3 of 4 | Engineer : Charles Passet
Date : 24/02/2019 | Revision :V2.0


Sheet 4 of 4 | Engineer : Charles Passet
Date : 24/02/2019 | Revision :2.0

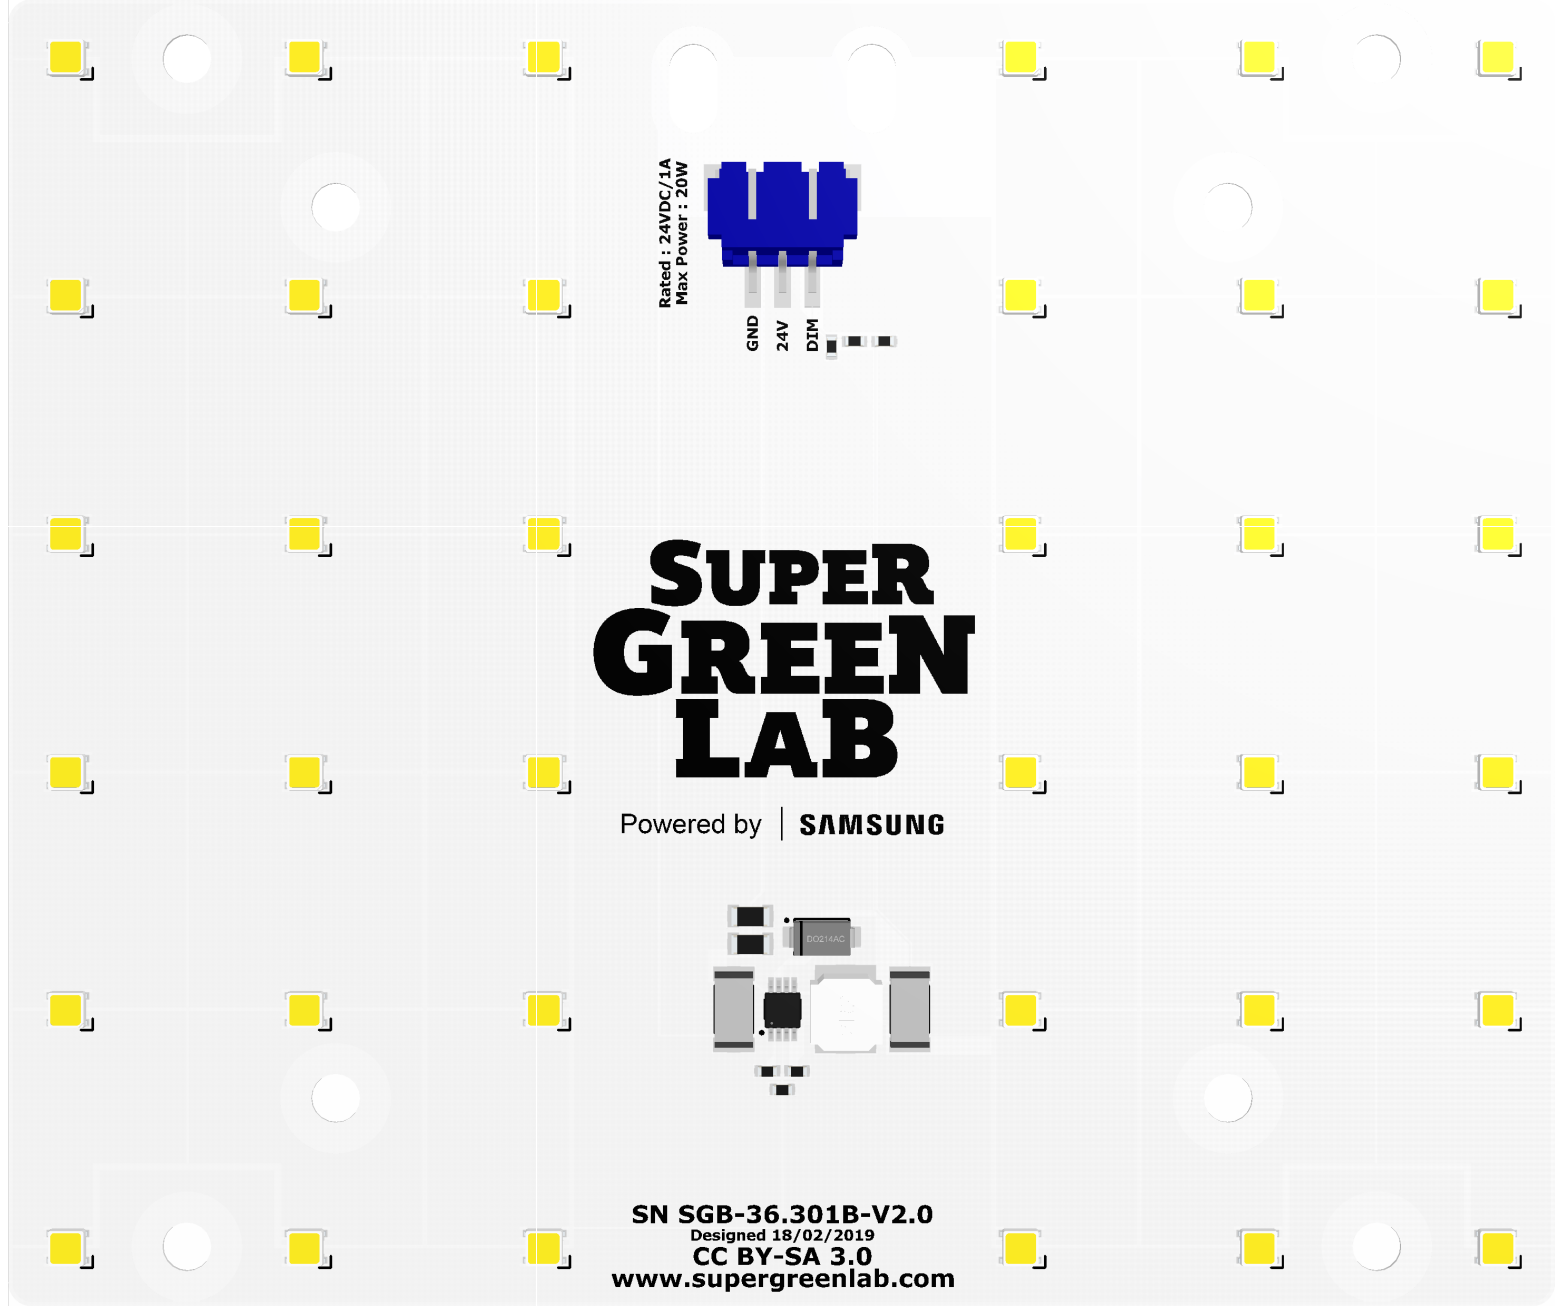
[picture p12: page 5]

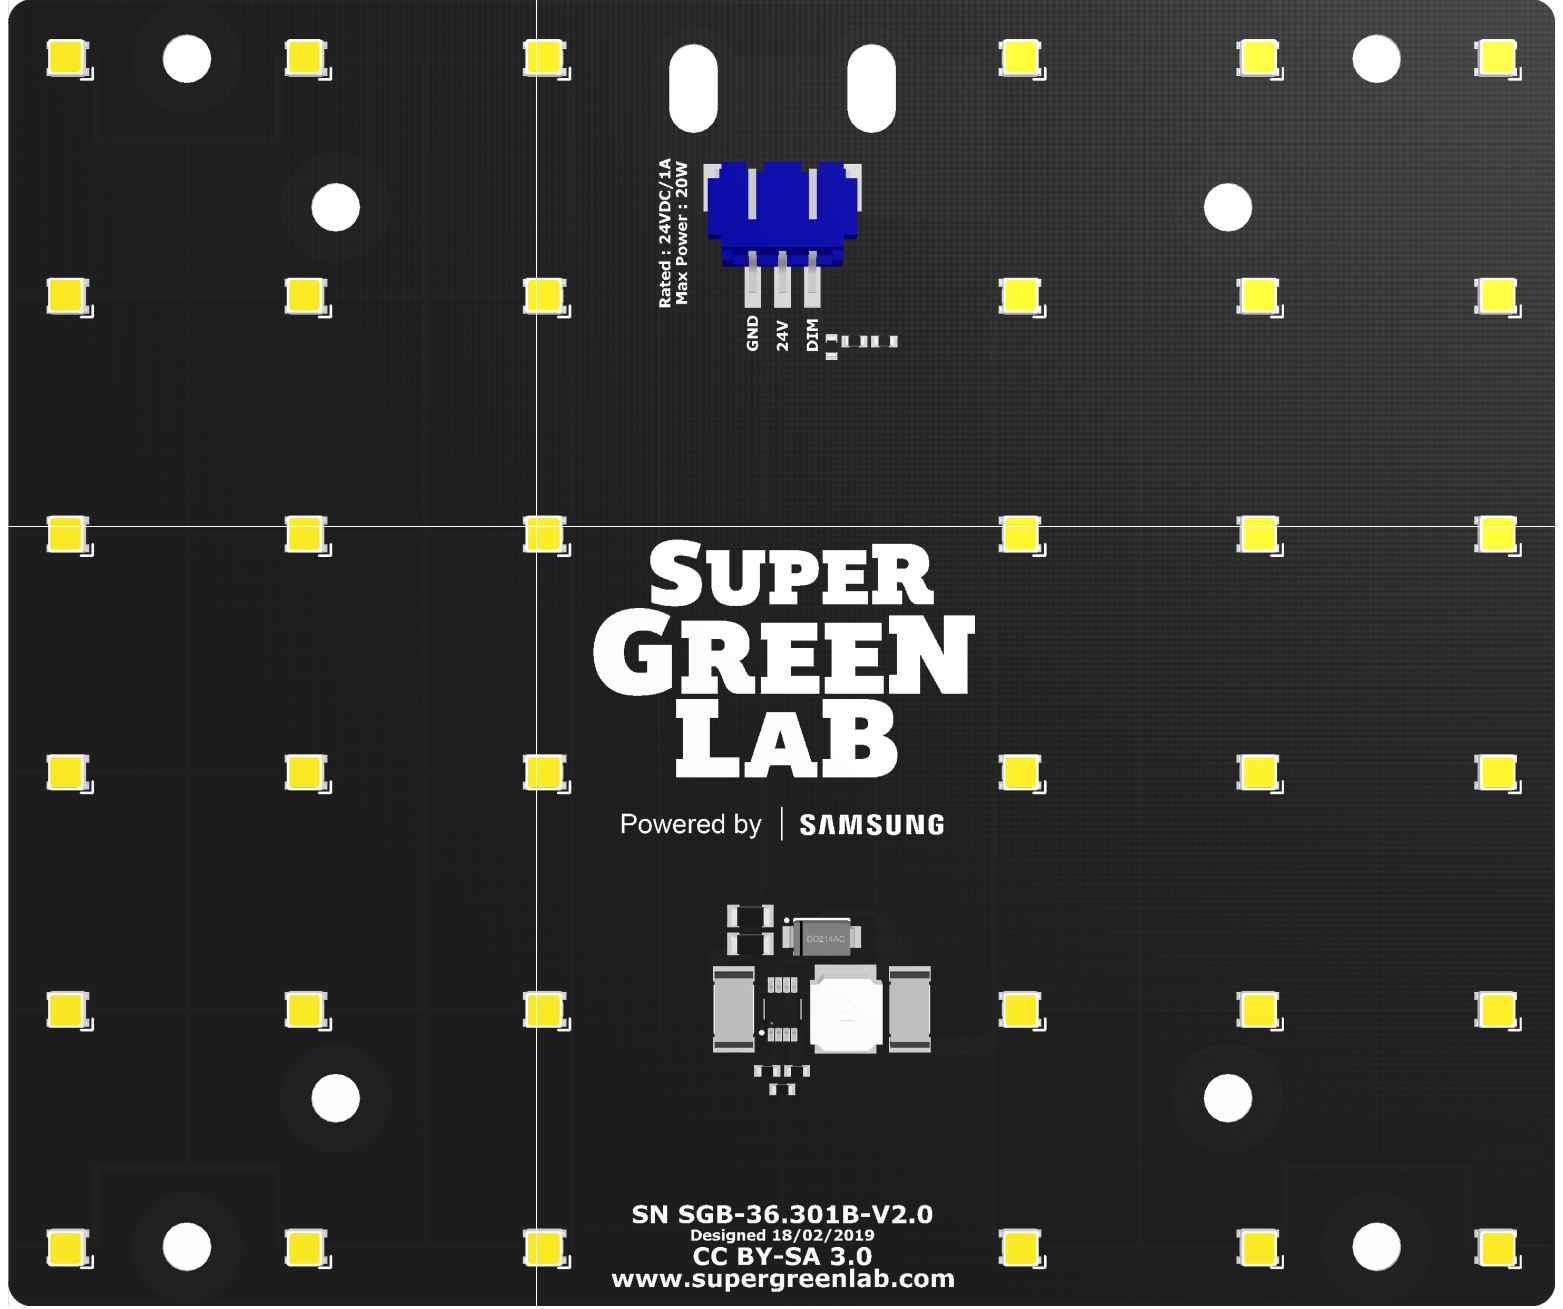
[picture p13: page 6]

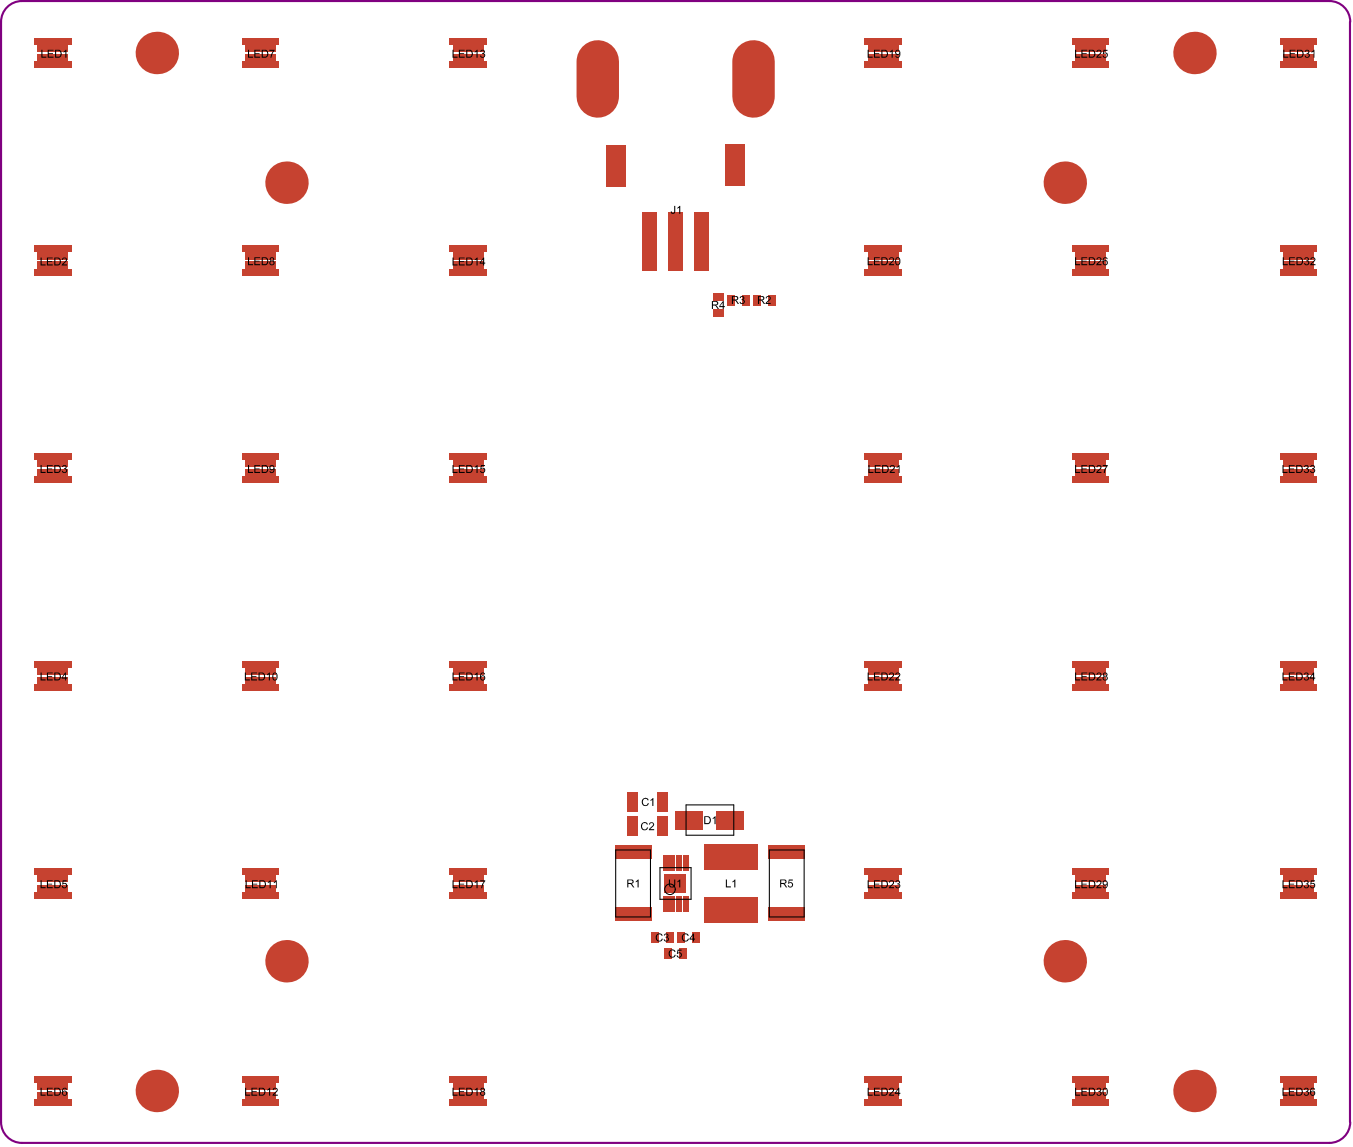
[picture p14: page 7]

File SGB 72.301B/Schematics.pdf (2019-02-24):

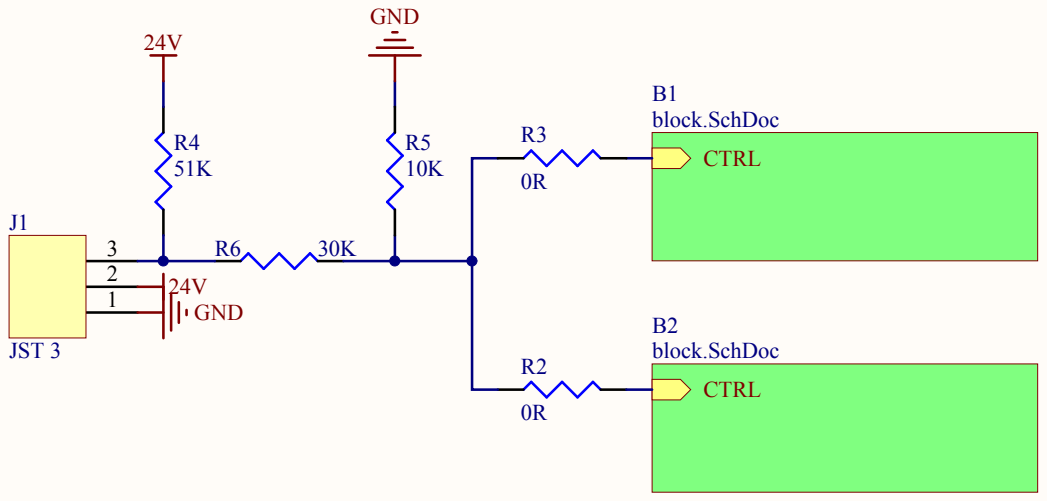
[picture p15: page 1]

Sheet 1 of 4 | Engineer : Charles Passet
Date : 24/02/2019 | Revision :V2.0


Sheet 2 of 4 | Engineer : Charles Passet
Date : 24/02/2019 | Revision :V2.0


Sheet 3 of 4 | Engineer : Charles Passet
Date : 24/02/2019 | Revision :V2.0


Sheet 4 of 4 | Engineer : Charles Passet
Date : 24/02/2019 | Revision :2.0




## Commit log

2019-01-05 changed leds in board overview
2019-01-05 added board picture
2019-01-05 added board pitcure
2019-02-19 added reddit button abd changed repo name
2019-02-24 Pushed V2.0
    [144.301B.DRL, 144.301B.GKO, 144.301B.GTL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]
2019-03-01 Added SGB 288
    [Bill of Materials-SGB 288.301B.xls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]
2019-03-01 updated 288 connector
2019-03-06 added SB 192.301B
    [Bill of Materials-SB 192.301B.xls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]
